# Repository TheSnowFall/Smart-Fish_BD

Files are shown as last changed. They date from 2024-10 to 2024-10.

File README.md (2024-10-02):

# Smart Fish BD IoT(Hardware & Firmware) Project 

This project consists of three main devices:

1. **SFBD_Gateway**  
2. **SFBD_Sensor_Unit**  
3. **SFBD_Switching_Unit**  

All codes are written using the Arduino IDE. The E32 module serves as the common communication hardware for all three devices. You can find more details about the E32 module [here](https://www.bdtronics.com/e32-433t30d-lora-433mhz-sx1278-10km-wireless-transmitter-and-receiver-uart-rf-module.html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).

## 1. SFBD_Gateway

For the gateway unit, the TTGO T-Call ESP32 wireless module was used.  
[TTGO T-Call ESP32 Module](https://store.roboticsbd.com/communication-module/1412-ttgo-t-call-esp32-wireless-module-gprs-antenna-sim-card-sim800l-board-robotics-bangladesh.html)

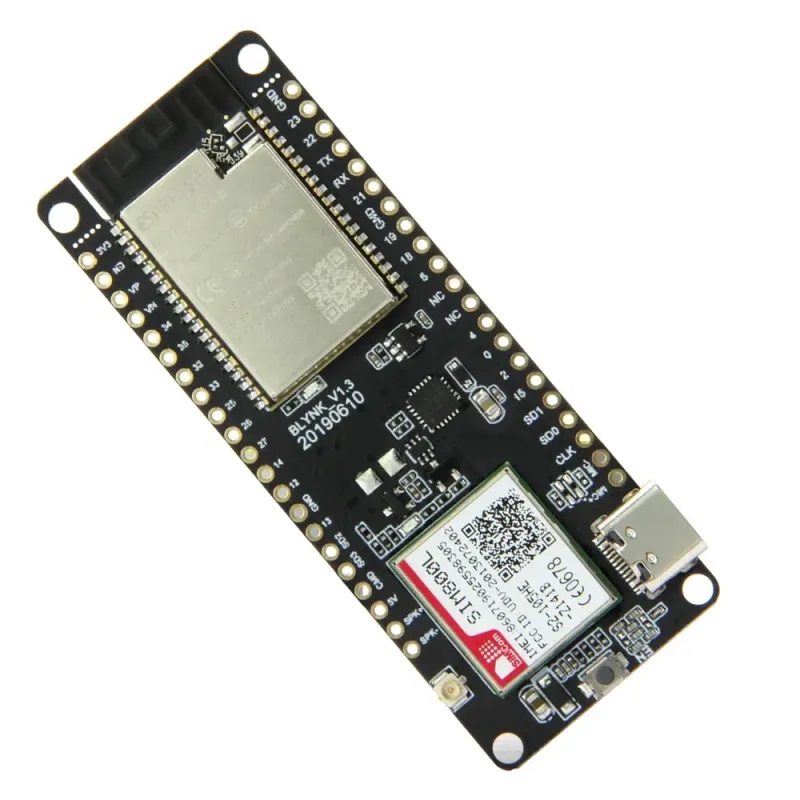
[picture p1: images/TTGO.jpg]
TTGO T-Call


## 2. SFBD_Switching_Unit

The switching unit uses the STM32 Bluepill microcontroller:  
[STM32 Bluepill](https://store.roboticsbd.com/development-boards/350-stm32f103c8t6-blue-pill-development-board-robotics-bangladesh.html)

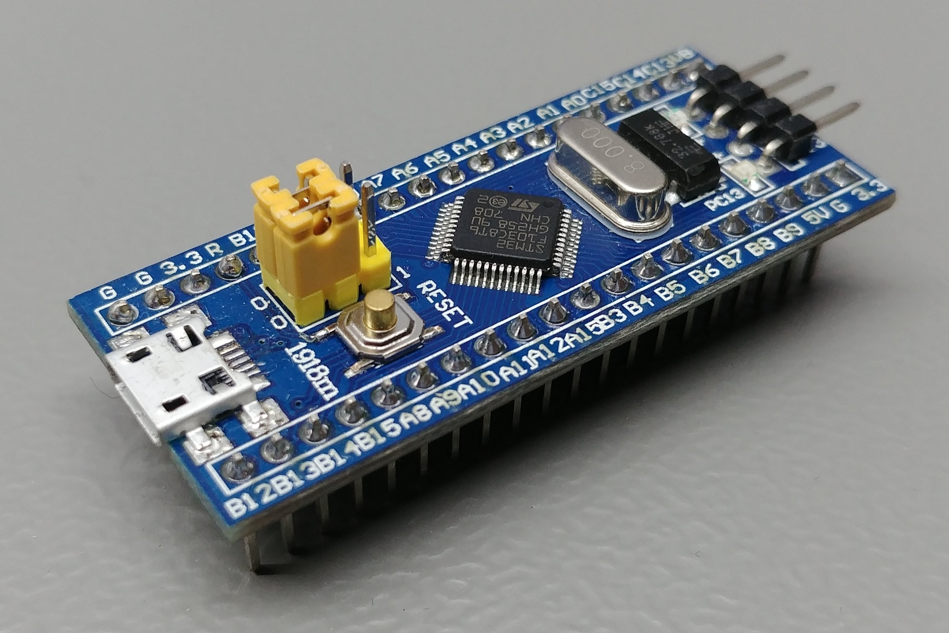
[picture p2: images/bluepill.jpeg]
Blue Pill


Additionally, it uses relay modules for switching:

- [8-Channel Relay Module](https://store.roboticsbd.com/relay/1948-8-channel-5v-relay-module-robotics-bangladesh.html)  

- [4-Channel Relay Module](https://store.roboticsbd.com/robotics-parts/409-4-channel-5v-relay-board-module-robotics-bangladesh.html)  

## 3. SFBD_Sensor_Unit

The sensor unit also uses the STM32 Bluepill microcontroller. This unit includes several sensors:

1. [DS18B20 Temperature Sensor](https://store.roboticsbd.com/robotics-parts/414-waterproof-ds18b20-digital-thermal-probe-or-sensor-robotics-bangladesh.html)
2. [DFRobot Dissolved Oxygen Sensor](https://techshopbd.com/detail/3472/Gravity:_Analog_Dissolved_Oxygen_Sensor___Meter__Kit_For_Arduino_techshop_bangladesh)
3. [DFRobot pH Sensor/Meter Kit V2](https://techshopbd.com/detail/3366/Gravity:_Analog_pH_Sensor_Meter_Kit_V2_techshop_bangladesh)
4. [Rain Sensor](https://techshopbd.com/detail/3502/Rain_Sensor_Module_techshop_bangladesh)
5. [DFRobot TDS Sensor/Meter for Arduino](https://techshopbd.com/detail/3294/Gravity:_Analog_TDS_Sensor_Meter_for_Arduino_techshop_bangladesh)

### Sensor Calibration

1. **pH Sensor:** Calibrated using the process described [here](https://wiki.dfrobot.com/Gravity__Analog_pH_Sensor_Meter_Kit_V2_SKU_SEN0161-V2).
2. **DO Sensor:** Calibrated using the two-point calibration method from [this link](https://wiki.dfrobot.com/Gravity__Analog_Dissolved_Oxygen_Sensor_SKU_SEN0237).
3. **TDS Sensor:** Calibrated using the process described [here](https://wiki.dfrobot.com/Gravity__Analog_TDS_Sensor___Meter_For_Arduino_SKU__SEN0244). A known TDS meter value was used as a reference for calibration.
4. **Temperature Sensor:** Corrected using a real thermometer by tweaking the constant value in the line:

    ```cpp
    temp = TempRead() * 0.0625;
    ```

   (Reference: `SFBD_sensor_unit/temperature.ino` line 4 in this GitHub project).

## Installing Dependencies for Arduino IDE

To use these codes in the Arduino IDE, you need to install the **ESP32** and **STM32** board support packages. Follow the instructions below:

1. Open Arduino IDE.
2. Go to **File > Preferences**.
3. In the "Additional Boards Manager URLs" field, add the following URLs:

    ```
    https://github.com/stm32duino/BoardManagerFiles/raw/main/package_stmicroelectronics_index.json
    https://raw.githubusercontent.com/espressif/arduino-esp32/gh-pages/package_esp32_index.json
    ```

4. Go to **Tools > Board > Boards Manager**, search for "ESP32" and "STM32", and install the respective packages.

### Selecting the Correct Board

- For the **gateway** codes, select the board: **ESP32 > ESP32 Wrover Module**.
- For the **sensor unit** and **switching unit** codes, select the board: **STM32 MCU based Board > Generic STM32F1 series**.

Upload the codes to their respective devices, and you're done!

## Gateway Configuration

**There are 2 cases:**

1. **If your device is brand new**, the following video is enough to configure.  
   You can find the gateway configuration guide video [here](https://drive.google.com/file/d/18WGI2CXndcDLMi8Di_tGigBhUmnVskKT/view?usp=sharing).

2. **If your device was connected to any WiFi previously and now you need to configure it again**, follow the steps:  
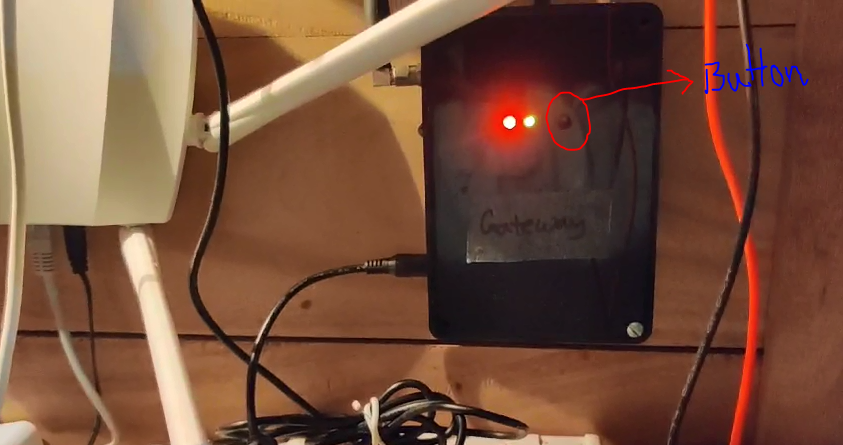
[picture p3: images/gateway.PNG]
   i.   
      See the marked area in the photo. There is a button that needs to be pressed with a pen for a minimum of **10 seconds**.

   ii. Now, follow the gateway configuration guide video [here](https://drive.google.com/file/d/18WGI2CXndcDLMi8Di_tGigBhUmnVskKT/view?usp=sharing).

## Circuit Board

All circuits were designed using an open-source software called Fritzing. You can download Fritzing from [this link](https://drive.google.com/file/d/1iceu7ZeL34dju8lppnuAEAwVtYvj-atZ/view?usp=sharing). The `.fzz` files in the repository are the Fritzing files.

Inside each folder, there is a zip file. Upload this zip file to TechShopPCB, and the circuit board manufacturing process is complete.

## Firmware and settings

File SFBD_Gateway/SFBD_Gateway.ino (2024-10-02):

#define TINY_GSM_MODEM_SIM800
#define SIM800L_IP5306_VERSION_20190610
#define WDT_TIMEOUT 15000
#define MAX_BUFFER_SIZE 20

#include <Arduino.h>
#include <WiFiManager.h>
#include <PubSubClient.h>
#include <TinyGsmClient.h>
#include "ArduinoNvs.h"
#include "OneButton.h"
#include <ESP32Ping.h>
#include <ArduinoJson.h>
#include "EBYTE.h"
#include "esp_task_wdt.h"


//Macro is done



#define GSM_PIN ""

#define SerialGeneric Serial
#define SerialAT Serial1
                                            // #define DUMP_AT_COMMANDS
#define TINY_GSM_DEBUG SerialGeneric

#ifdef DUMP_AT_COMMANDS
#include <StreamDebugger.h>
StreamDebugger debugger(SerialAT, SerialGeneric);
TinyGsm modem(debugger);
#else
TinyGsm modem(SerialAT);
#endif

#include "utilities.h"

bool gsm_task_flag = false;
bool wifi_fail_flag = false;
bool printed_gprs_tag = false;
bool printed_wifi_tag = false;
char apNameChar[32];
char apNameCharMqtt[32];
int timeout = 120;
String apn_id;
uint8_t mac[6];
char gd_id[18];

// ############################  Inserting variable regarding MQTT  ############################

char *broker = "68.183.231.35";
// char *topicLed = "tushar/mqtt_test";
// char *topicLedStatus = "tushar/go";
// char subscribe_topic[13] = { 0,};
// char publish_topic[13] = { 0, };
char* subscribe_topic;
char* publish_topic;
const char* relay_response_to_server;
const char* sensor_data_to_server;

// ############################  Inserting variable regarding MQTT  ############################
const char *remote_host = "www.google.com";

// ############################  Inserting variable regarding GPRS  ###########################
char apn[15] = {0,};
bool apnIsEmpty = true;
const char gprsUser[] = "";
const char gprsPass[] = "";

// ############################  Inserting variable regarding GPRS  ###########################


int ledStatus = LOW;
uint32_t lastReconnectAttempt = 0;

int customFieldLength = 40;

// ############################  WiFi Connect/disconnect timing variables  ###########################
unsigned long previousMillis = 0;
int retryCount = 0;
// ############################  WiFi Connect/disconnect timing variables  ###########################

// ############################  Button variables  ###########################
unsigned long pressStartTime = 0;
bool reset_setting = false;
bool single_press = false;
// ############################  Button variables  ###########################
// ######## Radio Transmission data ######## 

byte payload_from_mqtt[4]   = {0,};
byte received_response[10]  = {0,};
byte received_sen_data[10]  = {0,};
byte received_relay_msg[4]  = {0,};

int relay_msg_index = 0; // Index to keep track of received bytes for payload[4]
int sen_data_index = 0; // Index to keep track of received bytes for sen_payload[10]

uint8_t payload_index = 0;
int channel_ebyte;
 
// ######## Radio Transmission data ########
byte mqtt_status_publish_done = false;
byte mqtt_status_gprs_publish_done = false ;
bool status_update = false;
//  ######### JSON Variable ############

uint8_t endbyte_sen = 0x22;
uint8_t endbyte_sw = 0x33;    
uint8_t sw_addr= 0x44 ;
uint8_t sen_addr= 0x26 ;
bool payload_received = false;

//  ######### JSON Variable ############

OneButton button(TRIGGER_PIN, true);

/* 
Change  the harsware serial 2 pins in BSP level of ESP32.
TX2 >>19  RX2 >>18 is used here.
*/

HardwareSerial ESerial(2);   
EBYTE Transceiver(&ESerial, PIN_M0, PIN_M1, PIN_AX);

WiFiClient client;
PubSubClient mqtt(client);

TinyGsmClient client_gprs(modem);
PubSubClient mqtt_gprs(client_gprs);

WiFiManager *wmPtr;

unsigned long startTime;
uint8_t Provision_status = 0;

enum wifi_conn_stat {
  NO_PROVITION_STAT = 0,
  NOT_PROVISIONED,
  PROVISIONED,
  GPRS_PROVISIONED,
  WIFI_PROVISIONED
};

// ############## Received sensor data variable ################

struct SensorData {
  uint8_t food;
  uint32_t tds;  // Changed to uint32_t to accommodate the full range
  uint8_t rain;
  uint32_t temp;  // Changed to uint32_t to accommodate the full range
  uint16_t o2;    // Changed to uint16_t to accommodate the full range
  uint8_t ph;
};

// ############## Received sensor data variable ################
void IRAM_ATTR checkTicks() {
  button.tick();
}

void setup() {
  subscribe_topic = (char*)malloc(20 * sizeof(char));
  publish_topic = (char*)malloc(20 * sizeof(char));

  delay(3000);
  WiFi.mode(WIFI_STA);
  WiFi.begin();
  delay(3000);

  NVS.begin();
  SerialGeneric.begin(115200);
  ESerial.begin(9600);
  SerialGeneric.println(F("\n#############      Starting Gateway, Smart Fish BD      #############"));
  SerialGeneric.println(F("#############      Developed By:Erfan Mahmud Tushar     #############"));
  SerialGeneric.println(F("#############      Firmware Version : 1.1.0             #############\n"));
  SerialGeneric.setDebugOutput(true);
  pinMode(LED_GPIO, OUTPUT);

  pinMode(PIN_M0, OUTPUT);
  pinMode(PIN_M1, OUTPUT);

  digitalWrite(PIN_M0, LOW);
  digitalWrite(PIN_M1, LOW);
  
  Transceiver.init();
  delay(2000);
  // Transceiver.PrintParameters();


  esp_task_wdt_init(WDT_TIMEOUT, true); // Enable panic so ESP32 restarts
  esp_task_wdt_add(NULL);

  attachInterrupt(digitalPinToInterrupt(TRIGGER_PIN), checkTicks, CHANGE);
  button.attachClick(singleClick);
  // button.attachDoubleClick(doubleClick);
  
  button.attachDuringLongPress(duringPress);
  



  set_apn();
  generateAPName();



  if (WiFi.SSID() == "" && apnIsEmpty == true) {

    Provision_status = NOT_PROVISIONED;
    Serial.println("Not provisioned, Hit the button once please");
  } else if (WiFi.SSID() == "" && apnIsEmpty == false) {

    Provision_status = GPRS_PROVISIONED;
    Serial.println("Provisioned but no WiFi is provisioned");

  } else if (WiFi.SSID() != "" && apnIsEmpty == true) {
   
    Provision_status = WIFI_PROVISIONED;
    Serial.println("Provisioned but no GPRS is provisioned");
  } else {
    Provision_status = PROVISIONED;
    Serial.println("Everything Provisioned,sit tight");
  }


  if (Provision_status == PROVISIONED) {
    Serial.println("I am inside fully provisioned");
    topic_ready();
    

    getting_sim_ready();

    mqtt.setServer(broker, 1883);
    mqtt.setCallback(mqttCallback);

    mqtt_gprs.setServer(broker, 1883);
    mqtt_gprs.setCallback(mqttCallback_gprs);
  }

  else if (Provision_status == WIFI_PROVISIONED) {
    Serial.println("I am inside only WiFi provisioned");
    topic_ready();
    mqtt.setServer(broker, 1883);
    mqtt.setCallback(mqttCallback);
  }

  else if (Provision_status == GPRS_PROVISIONED) {
    Serial.println("I am inside only GPRS provisioned");
    topic_ready();
    getting_sim_ready();
    mqtt_gprs.setServer(broker, 1883);
    mqtt_gprs.setCallback(mqttCallback_gprs);
  }

  else{
    // ??
  }

 blinkLED(2,100);
}

void loop() {
  button.tick();

  if (reset_setting == true) {
    single_press = true;
  }


//   if (ESerial.available() > 1) {
//   Serial.print("Received Data:");
//   for (int i = 0; i < 4; i++) {
//     received_response[i] = ESerial.read();
//     if (i == 1 || i == 2) {
//       Serial.print(" | 0b");
//       printBinary(received_response[i]);
//     } else {
//       Serial.print(" | 0x");
//       Serial.print(received_response[i], HEX);
//     }
//   }
//   Serial.println(" ");
// } 


 processEbyteSerial();


  // wifi_manager
  if (single_press == true || Provision_status == NOT_PROVISIONED) {
    startTime = millis();
    WiFiManager wm;
    wmPtr = &wm;

    if (reset_setting == true) {
      SerialGeneric.println("Erasing Config, restarting");
      erase_apn() ;         //Erase APN
      wm.resetSettings();  // Reset WiFiManager settings
      ESP.restart();       // Restart ESP32
    }

    const char *mobile_operator = "<br/><label for='customfieldid'><b>Select your SIM operator:</b></label><br><input type='radio' name='customfieldid' value='1' checked> Grameenphone<br><input type='radio' name='customfieldid' value='2'> Robi<br><input type='radio' name='customfieldid' value='3'> Banglalink<br><input type='radio' name='customfieldid' value='4'> Teletalk<br><input type='radio' name='customfieldid' value='5'> Airtel";
    WiFiManagerParameter custom_field(mobile_operator);
    wm.addParameter(&custom_field);
    wm.setSaveParamsCallback(saveParamCallback);
    const char *menu[] = { "param", "wifi", "info", "sep", "restart", "exit" };
    wm.setMenu(menu, 6);
    wm.setClass("invert");
    wm.setConfigPortalTimeout(timeout);
    bool res;
    generateAPName();
    res = wm.autoConnect(apNameChar);

    if (!res) {
      SerialGeneric.println("failed to connect and hit timeout");
      delayPassed(3000);
      ESP.restart();
      delayPassed(5000);
    }
    SerialGeneric.println("connected...yeey :)");
    single_press = false;
    esp_restart();
  }

  if (Provision_status == PROVISIONED) {
    if ((WiFi.status() != WL_CONNECTED) || (Ping.ping(remote_host) == false)) {
      wifi_fail_flag = true;
      gsm_task_flag = true;
      goto gprs_mqtt;
    } else {
      wifi_fail_flag = false;
      gsm_task_flag = false;
      goto wifi_mqtt;
    }
  }

  else if (Provision_status == WIFI_PROVISIONED) {
    wifi_fail_flag = false;
    gsm_task_flag = false;
    mqtt_gprs.disconnect();
    goto wifi_mqtt;
  } else if (Provision_status == GPRS_PROVISIONED) {
    wifi_fail_flag = true;
    gsm_task_flag = true;
    mqtt.disconnect();
    goto gprs_mqtt;
  }

  else{
    Serial.println("Not provisioned yet!");
  }

gprs_mqtt:
  if (gsm_task_flag == true && wifi_fail_flag == true) {\
   
    if (!printed_gprs_tag) {
      SerialGeneric.println("########### MQTT IN GPRS #############");
      printed_gprs_tag = true;
    }
    if (!mqtt_gprs.connected()) {
      SerialGeneric.println("=== MQTT NOT CONNECTED G===");
      uint32_t t = millis();
      if (t - lastReconnectAttempt > 10000L) {
        lastReconnectAttempt = t;
        if (mqttConnect_gprs()) {
          lastReconnectAttempt = 0;
        }
      }
      delayPassed(100);
      return;
    }
    mqtt_gprs.loop();
  }

wifi_mqtt:
  if (gsm_task_flag == false && wifi_fail_flag == false) {
      
    if (!printed_wifi_tag) {
      SerialGeneric.println("########### MQTT IN WiFi #############");
      printed_wifi_tag = true;
    }
    if (!mqtt.connected()) {
      SerialGeneric.println("=== MQTT NOT CONNECTED W===");
      uint32_t t = millis();
      if (t - lastReconnectAttempt > 10000L) {
        lastReconnectAttempt = t;
        if (mqttConnect()) {
          lastReconnectAttempt = 0;
        }
      }
      delayPassed(100);
      return;
    }
    mqtt.loop();
  }
}

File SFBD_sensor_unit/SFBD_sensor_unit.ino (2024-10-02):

#include <Arduino.h>
#include <EEPROM.h>
#include <STM32RTC.h>
#include "DFRobot_PH.h"
#include "GravityTDS.h"

// ################# pin_def #################

#define DO_PIN PA1
#define PH_PIN PA0


#define TDS_PIN PA4
#define TEMP_PIN PA5

#define RAIN_PIN PB0
#define PUMP_PIN PB11


// #define FOOD_EMPTY    PB11
// #define FOOD_MEDIUM   PB10
// #define FOOD_FULL     PB1

// ################# pin_def #################

// ################# temp #################
double temp;
// ################# temp #################

// ################# ph #################
uint8_t phValue;
float voltage;
DFRobot_PH ph;
// ################# ph #################


// ################# TDS #################
float tdsValue = 0;
float sensorValue = 0;
GravityTDS gravityTds;
// ################# TDS #################


// ################# D.O #################


//Single-point calibration Mode=0
//Two-point calibration Mode=1
#define TWO_POINT_CALIBRATION 1


#define CAL1_V  (975)//mv
#define CAL1_T   (34) //℃


#define CAL2_V  (698)//mv
#define CAL2_T   (25) //℃

const uint16_t DO_Table[41] = {
    14460, 14220, 13820, 13440, 13090, 12740, 12420, 12110, 11810, 11530,
    11260, 11010, 10770, 10530, 10300, 10080, 9860, 9660, 9460, 9270,
    9080, 8900, 8730, 8570, 8410, 8250, 8110, 7960, 7820, 7690,
    7560, 7430, 7300, 7180, 7070, 6950, 6840, 6730, 6630, 6530, 6410};

uint8_t Temperaturet;
uint16_t ADC_Raw;
uint16_t ADC_Voltage;
uint16_t DO;

// ################# D.O ################# 


unsigned long idleTime = 10 * 60 * 1000;  // 10 minutes in milliseconds
unsigned long pumpTime = 3 * 60 * 1000;   // 3 minuites in milliseconds
unsigned long sensorRunTime = 8* 60 * 1000; // 8 minuite in milliseconds

unsigned long lastIdleTime = 0;
unsigned long lastPumpTime = 0;
unsigned long sensorStartTime = 0;
bool isIdle = true;
bool pumpOn = false;
bool runningSensors = false;
bool firstTimePull = true;



// ################# Timer #################

// ################# filter #################
const int numReadings = 10; // Adjust this value as needed

int readings[numReadings];   // Array to store the readings
int filter_index = 0;               // Index of the current reading
int filter_total = 0;               // Running total of the readings
int filter_average = 0;             // Smoothed average value

// ################# filter #################


#define VREF 3300     //VREF (mv)
#define ADC_RES 1024  //ADC Resolution

HardwareSerial LoRa(USART2);
// Define the structure to hold the sensor data
struct SensorData {
  uint8_t food;
  uint32_t tds;  // Changed to uint32_t to accommodate the full range
  uint8_t rain;
  uint32_t temperature;  // Changed to uint32_t to accommodate the full range
  uint16_t o2;           // Changed to uint16_t to accommodate the full range
  uint8_t ph;
};

// Global variable for the payload
byte sen_payload[10];  // Total size of sen_payload according to specification

SensorData prev_sensorData;  // Previous sensor data for comparison
SensorData sensorData;
// Function to pack the sensor data into the sen_payload array


void setup() {
  Serial.begin(115200);
  analogReadResolution(10);
  LoRa.begin(9600);

  sensorData.o2 = 0;
  sensorData.ph = 0;
  sensorData.rain = 1;
  sensorData.food = 0;
  sensorData.tds = 0;
  sensorData.temperature=0;


  for (int thisReading = 0; thisReading < numReadings; thisReading++) {
    readings[thisReading] = 0;
  }

  ph.begin();
  gravityTds.setPin(TDS_PIN);

  gravityTds.setAref(3.3);       //reference voltage on ADC, default 5.0V on Arduino UNO
  gravityTds.setAdcRange(1024);  //1024 for 10bit ADC;4096 for 12bit ADC
  gravityTds.begin();            //initialization


  pinMode(RAIN_PIN, INPUT);
  pinMode(PUMP_PIN, OUTPUT);
  digitalWrite(PUMP_PIN, LOW);
  // pinMode(FOOD_EMPTY, INPUT);
  // pinMode(FOOD_MEDIUM, INPUT);
  // pinMode(FOOD_FULL, INPUT);

  Serial.println("########  Starting Sensor Unit  ##########");
}

// Global variables for pump timing


void loop() {
  processEbytLoRaSerial();
  unsigned long currentMillis = millis();


  if (firstTimePull) {
      isIdle = false;
      firstTimePull= false;
      pumpOn = true;
      lastPumpTime = currentMillis;
      digitalWrite(PUMP_PIN, HIGH);  // Turn the pump on
    
  }



  // Handle idle mode (idle time)
if (isIdle) {
    if (currentMillis - lastIdleTime >= idleTime) {
      isIdle = false;
      lastPumpTime = currentMillis;
      pumpOn = true;
      digitalWrite(PUMP_PIN, HIGH);  // Turn the pump on
    } else {
      // Remain idle during idle time
      return;
    }
  }





  // Handle pump on time
  if (pumpOn ) {
    if (currentMillis - lastPumpTime >= pumpTime) {
      pumpOn = false;
      digitalWrite(PUMP_PIN, LOW);  // Turn the pump off

      // Start sensor functions for 30 seconds
      runningSensors = true;
      sensorStartTime = currentMillis;
    }
    return;
  }
   if (runningSensors) {
    if (currentMillis - sensorStartTime < sensorRunTime) {
      temperature();
      dissolve_o2_sen();
      ph_count();
      tds_count();
      rain();
    } else {
      runningSensors = false;

      // After sensor functions run, execute the data packing and transmission
      packSensorData(sensorData);

      // Print the packed payload
      Serial.println("Packed Payload:");
      for (int i = 0; i < 10; i++) {
        LoRa.write(sen_payload[i]);
        Serial.print(sen_payload[i], HEX);  // Print in hexadecimal format
        Serial.print(" ");
      }
      Serial.println();

      // Update previous sensor data for comparison
      prev_sensorData = sensorData;

      // Unpack sen_payload into sensor data
      SensorData unpackedData;
      unpackSensorData(unpackedData);

      // Print the unpacked sensor data
      Serial.println("Unpacked Sensor Data:");
      printSensorData(unpackedData);

      // Reset idle time
      isIdle = true;
      lastIdleTime = currentMillis;
    }
    return;
  }
}

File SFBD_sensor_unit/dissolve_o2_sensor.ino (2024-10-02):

int16_t readDO(uint32_t voltage_mv, uint8_t temperature_c)
{
#if TWO_POINT_CALIBRATION == 0
  uint16_t V_saturation = (uint32_t)CAL1_V + (uint32_t)35 * temperature_c - (uint32_t)CAL1_T * 35;
  return (voltage_mv * DO_Table[temperature_c] / V_saturation);
#else
  uint16_t V_saturation = (int16_t)((int8_t)temperature_c - CAL2_T) * ((uint16_t)CAL1_V - CAL2_V) / ((uint8_t)CAL1_T - CAL2_T) + CAL2_V;
  return (voltage_mv * DO_Table[temperature_c] / V_saturation);
#endif
}


void dissolve_o2_sen() {

  Temperaturet = (uint8_t)temp;
  filter_total = filter_total - readings[filter_index];
  readings[filter_index] = analogRead(DO_PIN);

  filter_total = filter_total + readings[filter_index];
  // advance to the next position in the array:
  filter_index = filter_index + 1;

  // if we're at the end of the array...
  if (filter_index >= numReadings) {
    // ...wrap around to the beginning:
    filter_index = 0;
  }
  ADC_Raw=filter_total/numReadings;


  ADC_Voltage = uint32_t(VREF) * ADC_Raw / ADC_RES;
  Serial.print("[DO]");
  Serial.print("DO:   ");
  Serial.print(readDO(ADC_Voltage, Temperaturet) / 1000.0);
  Serial.print("mg/L");
  Serial.println();

  uint16_t o2_measures_by_prob = readDO(ADC_Voltage, Temperaturet) / 1000.0 * 100;

 sensorData.o2 = o2_measures_by_prob;


  // uint8_t o2_difference = (o2_measures_by_prob > prev_sensorData.o2) ? (o2_measures_by_prob - prev_sensorData.o2) : (prev_sensorData.o2 - o2_measures_by_prob);
  // Serial.print(",  o2_difference:");
  // Serial.println(o2_difference);
  // delay(100);

  // (o2_difference > 30) ? (sensorData.o2 = o2_measures_by_prob) : Serial.println("No change in D.O values");
}

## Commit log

2024-03-29 Switching unit fully functional
    1. Send 12 bit as 111111111111.
    2. Also sends the response as it already executed given command
2024-04-02 sim added but not works
    [SFBD_Gateway.ino, button.ino, misc.ino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]
2024-04-06 Json to relay payload is working.
    server to relay command works perfectly
2024-04-06 response can be received from lora relay
2024-04-06 switching unit is changed a bit
2024-04-07 topic issue solved, long press solved
    [SFBD_Gateway.ino, SFBD_sensor_unit.ino, SFBD_switching_unit.ino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]
2024-04-07 relay response publish is working
2024-04-08 both publish for relay response updated..but with gprs it is not working to send data
    [misc.ino, mqtt.ino]
2024-04-09 publish sensor data works perfectly
2024-04-09 pub sub changed , relay address changed working properly.
2024-04-15 pin change for M1 and M0
2024-04-16 3 sensors done need to add in main code
2024-04-21 sensor part complete
2024-10-02 all files are responsible to SFBD timer option for sensors
2024-10-02 PCB files are uploaded
    [SFBD_Gateway.fzz, SFBD_Sensor.fzz, SFBD_Switch.fzz]
